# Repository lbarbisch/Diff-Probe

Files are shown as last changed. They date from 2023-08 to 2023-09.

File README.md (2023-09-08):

# Diff-Probe

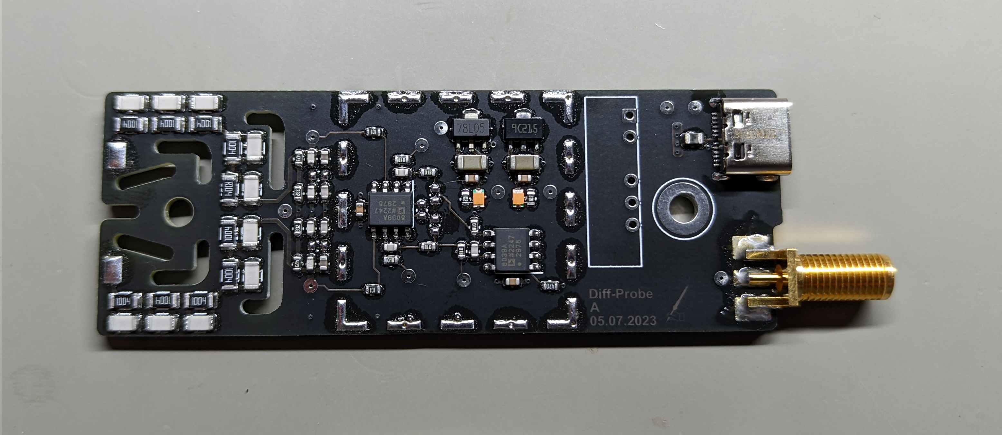
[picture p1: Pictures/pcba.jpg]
Circuit Board


## Overview
The goal of this project was to create a relatively cheap and simple differential probe, intended mostly for hobbyists and makers.

## Specification
This probe has a voltage rating of ±500V on each input, which means a differential rating of ±1000V.  
Depending on the opamps the usable bandwith can be in excess of 10 MHz.  

The power supply is done via a USB-C connector and a DC/DC converter for galvanic isolation.

I've tried two different opamps, with whom the Diff-Probe can reach the following bandwidths:

| Opamp  | Opamp bandwith | Probe bandwidth | Cost per opamp |
| -----  | --- | --- | --- |
| TL072  | 3MHz | ~1MHz | <0.20$ |
| AD8039 | 350MHz | ~18MHz | ~2.50$ |

## Cost
All the components cost about 20 to 25 USD with the more expensive opamp option.

## Housing
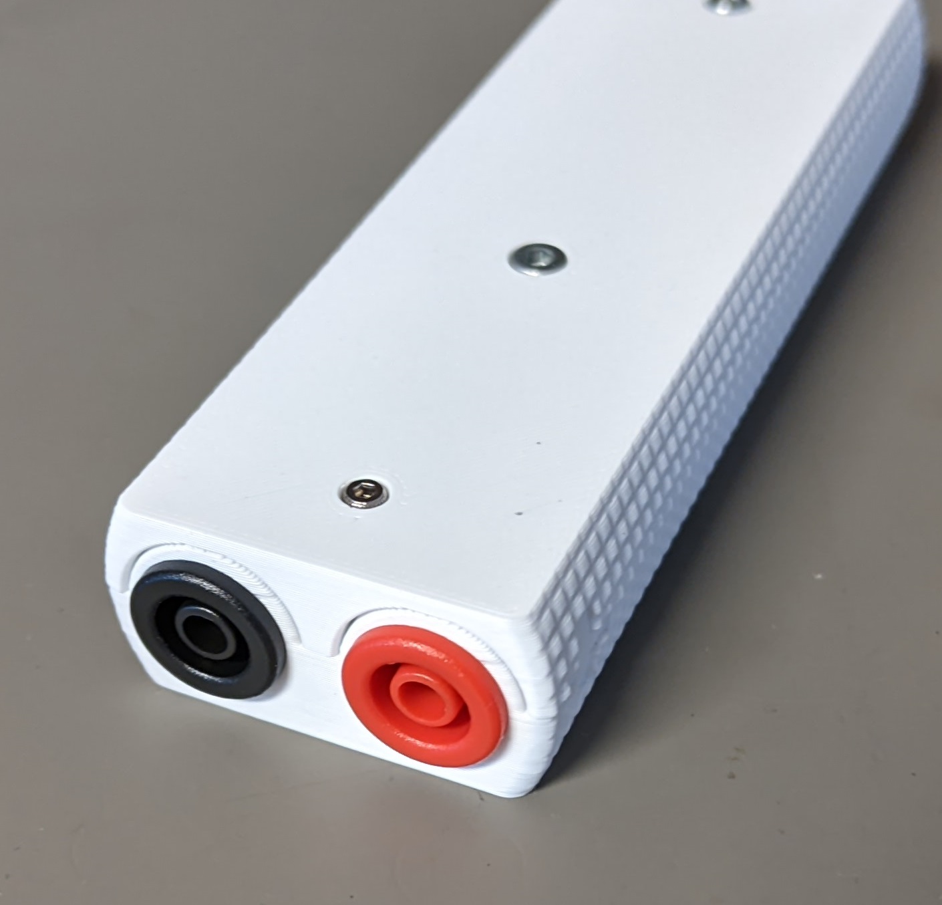
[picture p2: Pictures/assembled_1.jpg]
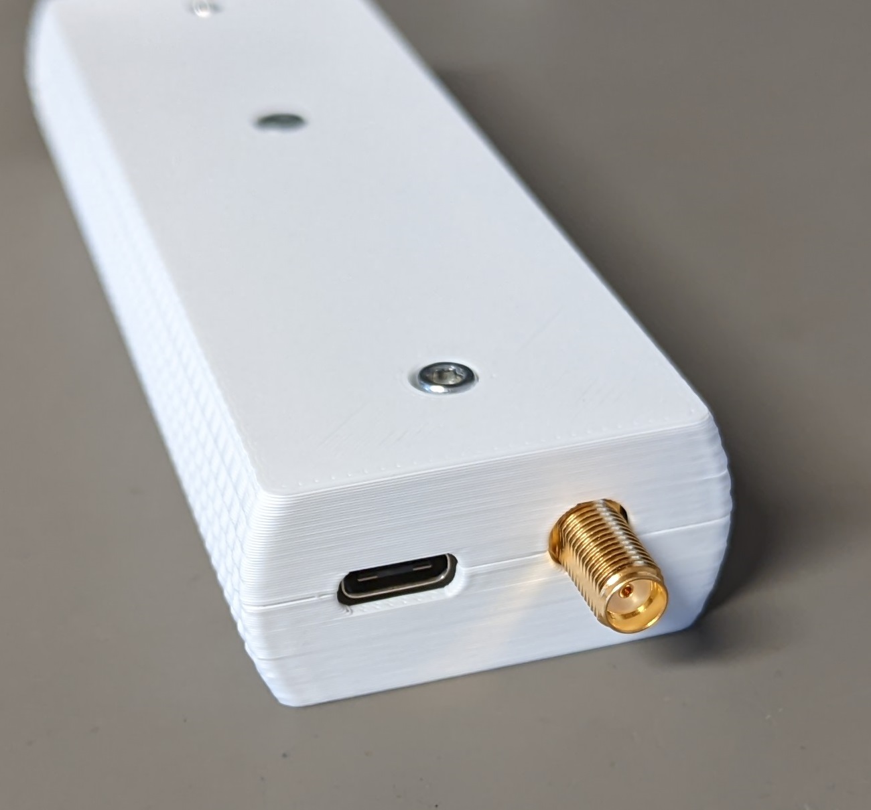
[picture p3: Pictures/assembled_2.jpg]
   
This housing is printed in ABS for durability, but can easily be printed in PLA.  
It is held together with two M3x10 and one M2x12 screw, which are each screwed into heat set inserts.  
The M2 screw can be omitted, but the housing will probably not fully close on that side and leave a small gap.

Assembly of the Diff-Probe:  
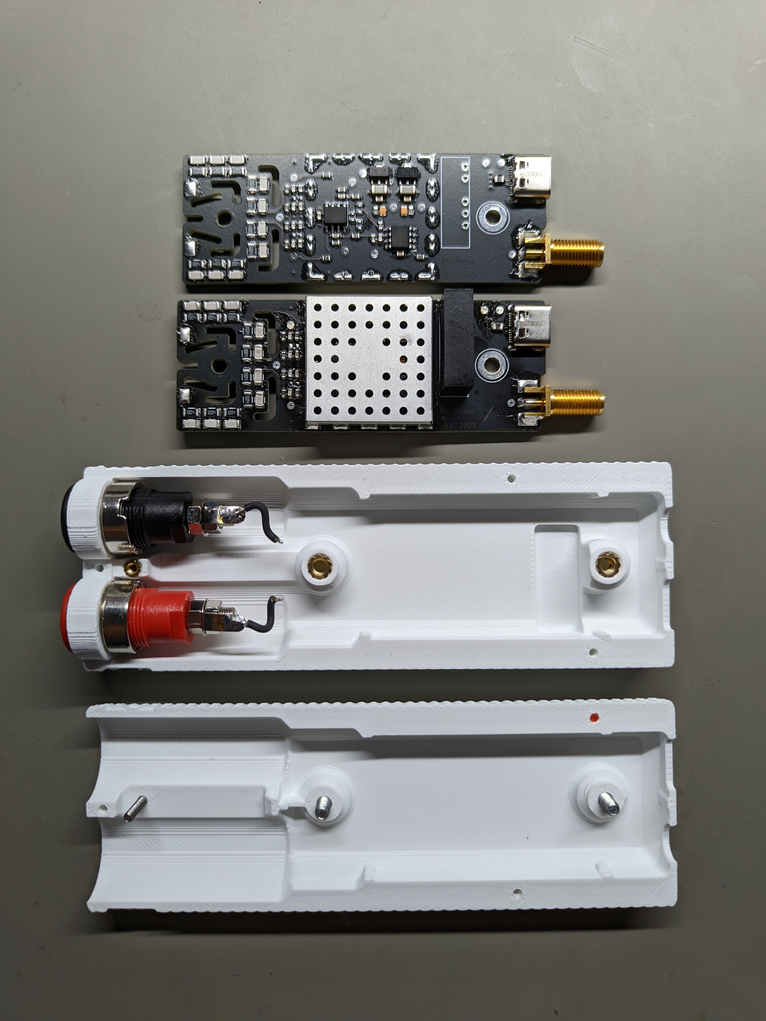
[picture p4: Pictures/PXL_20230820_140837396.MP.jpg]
  

## Files
[Schematic](/PCB/OUTPUT/Diff-Probe_A00_SCH.PDF)  
[Assembly Drawing](/PCB/OUTPUT/Diff-Probe_A00_PCBA.PDF)  
[Bill of Material](/PCB/OUTPUT/Diff-Probe_A00_BOM.xlsx)  

[CAD for Housing](/Housing/)

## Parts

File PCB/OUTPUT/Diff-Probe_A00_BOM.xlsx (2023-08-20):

Bill of Materials
Project: |  | Diff-Probe.PrjPcb
Variant: |  | 951.xxxx
 |  | Base Variant
Revision: |  | A
Creation Date: | 20.08.2023 | 14:23
Print Date: | 2023-08-20 | 14:27:20
 |  | Designator | Quantity | Description | Manufacturer | Manufacturer Part Number | Footprint | ClassName
 |  | C1, C2, C3, C4, C5, C19, C20, C21, C22, C23 | 10 | CAP CER 10PF 1KV U2J 1206 |  |  | C-1206_3216_100_L_RF | Surface_Assy
 |  | C7, C11, C13, C17 | 4 | Cap Cer SMD 10p 50V +/- 0.25pF 0603 C0G | AVX | 06035A100CAT* | C-0603_1608_095_L_RF | Surface_Assy
 |  | C8, C18 | 2 | Cap Cer SMD 470p 100V 10% 0603 X7R | AVX | 06031C471KAT2A | C-0603_1608_095_L_RF | Surface_Assy
 |  | C10, C16, C25 | 3 | Cap Cer SMD 22p 50V 5% 0603 C0G | AVX | 06035A220JAT | C-0603_1608_095_L_RF | Surface_Assy
 |  | C12, C14 | 2 | Cap Cer SMD 330p 50V 2% 0603 C0G | MURATA | GRM1885C1H331GA01D | C-0603_1608_095_L_RF | Surface_Assy
 |  | C26, C27, C29, C31, C34, C38, C41 | 7 | Cap Cer SMD 100n 100V 10% 0603 X7R | MURATA | GRM188R72A104KA35 | C-0603_1608_095_L_RF | Surface_Assy
 |  | C28, C30, C33, C37, C40 | 5 | Cap Cer SMD 10u 6.3V 10% 0805 X7R | MURATA | GCM21BR70J106KE22 | C-0805_2012_155_L_RF | Surface_Assy
 |  | C32, C39 | 2 | Cap Cer SMD 100u 6.3V 20% 1206 X5R | AVX | 12066D107MAT2A | C-1206_3216_180_L_RF | Surface_Assy
 |  | C35, C42 | 2 | Cap Cer SMD 1n 50V 1% 0603 C0G | AVX | 06035A102FAT* | C-0603_1608_100_L_RF | Surface_Assy
 |  | C36, C43 | 2 | Cap Cer SMD 100p 50V 5% 0603 C0G | YAGEO | CC0603J*NPO9BN101 | C-0603_1608_095_L_RF | Surface_Assy
 |  | D1, D2 | 2 | LED Green LTST-C190KGKT 0603 | Lite-On Inc | LTST-C190KGKT | LED-0603_1608_Green_L_RF | Surface_Assy
 |  | N1, N2 | 2 | IC OPAMP JFET 3MHZ 8SOIC | Texas Instruments | TL072IDR | SO8_L_RF | Surface_Assy
 |  | PCB1 | 1 | <PCB DesignName Revision> |  |  | Dummy_PCB-Parameter_SM | Symbol
 |  | R1, R2, R3, R4, R5, R19, R20, R21, R22, R23 | 10 | Res SMD 1M 1% 0.25W 1206 | YAGEO | RC1206FR-071ML | R-1206_3216_065_L_RF | Surface_Assy
 |  | R6, R17 | 2 | Res SMD 100R 1% 0.1W 0603 | YAGEO | RC0603FR-07100RL | R-0603_1608_050_L_RF | Surface_Assy
 |  | R7, R9, R10, R15, R18, R24, R26, R27 | 8 | Res SMD 1k 1% 0.1W 0603 | YAGEO | RC0603FR-071KL | R-0603_1608_050_L_RF | Surface_Assy
 |  | R8, R16 | 2 | Res SMD 47k 1% 0.1W 0603 | YAGEO | RC0603FR-0747KL | R-0603_1608_050_L_RF | Surface_Assy
 |  | R11, R14 | 2 | Res SMD 3k3 1% 0.1W 0603 | YAGEO | RT0603FRE073K3L | R-0603_1608_050_L_RF | Surface_Assy
 |  | R12 | 1 | Res SMD 47R 1% 0.1W 0603 | YAGEO | RC0603FR-0747RL | R-0603_1608_050_L_RF | Surface_Assy
 |  | R25 | 1 | Res SMD 0R 1% 0.125W 0805 | YAGEO | RC0805JR-070RL | R-0805_2012_060_L_RF | Surface_Assy
 |  | R28, R29 | 2 | Res SMD 5k1 1% 0.1W 0603 | YAGEO | RC0603FR-075K1L | R-0603_1608_050_L_RF | Surface_Assy
 |  | U1 | 1 | IC DC/DC Converter 5VIN +-9VOUT 1W | XP Power | IA0509S | SIP7 | Through-Hole_Assy
 |  | V1, V2, V3, V4 | 4 | Diode Schottky 40V 1A SMA | VISHAY | SS14-E3 | SMA_DO214AC_L_RF | Surface_Assy
 |  | V5 | 1 | IC REG 5V SOT-89-3 | ST | L78L05 | SOT-89-3 | Surface_Assy
 |  | V6 | 1 | IC REG -5V SOT-89-3 | ST | L79L05 | SOT-89-3 | Surface_Assy
 |  | X2 | 1 | EMI Shield 26.2mm x 26.2mm, soldered | Laird | BMI-S-103 | BMI-S-103 | Surface_Assy | Testpoint | Through-Hole_Assy | NetTie | Symbol | Mechanical
 |  | X3 | 1 | CONN USB-C 16pin | Molex | 105450-0101 | 105450-0101 | Through-Hole_Assy
 |  | X4 | 1 | CONN RF SMA | MOLEX | 73251-2120 | 73251-2120 | Through-Hole_Assy
 |  |  | 82

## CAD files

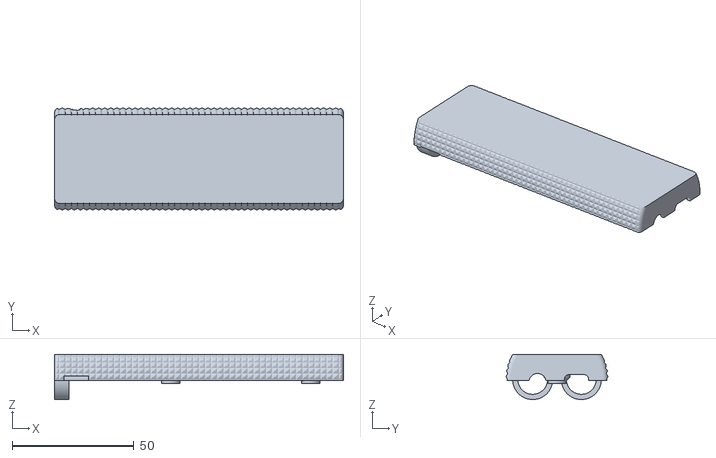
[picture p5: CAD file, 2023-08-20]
Housing/case_knurls - Part 2.stl
118.9 x 41.9 x 18.6

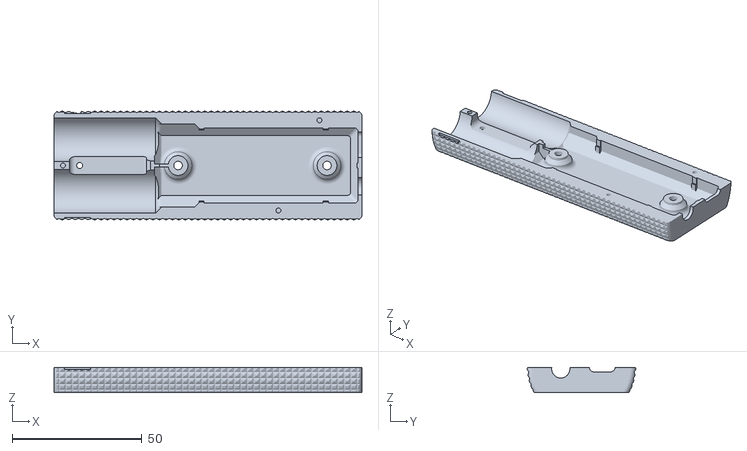
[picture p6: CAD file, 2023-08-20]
Housing/case_knurls - Part 1.stl
118.9 x 41.9 x 9.75

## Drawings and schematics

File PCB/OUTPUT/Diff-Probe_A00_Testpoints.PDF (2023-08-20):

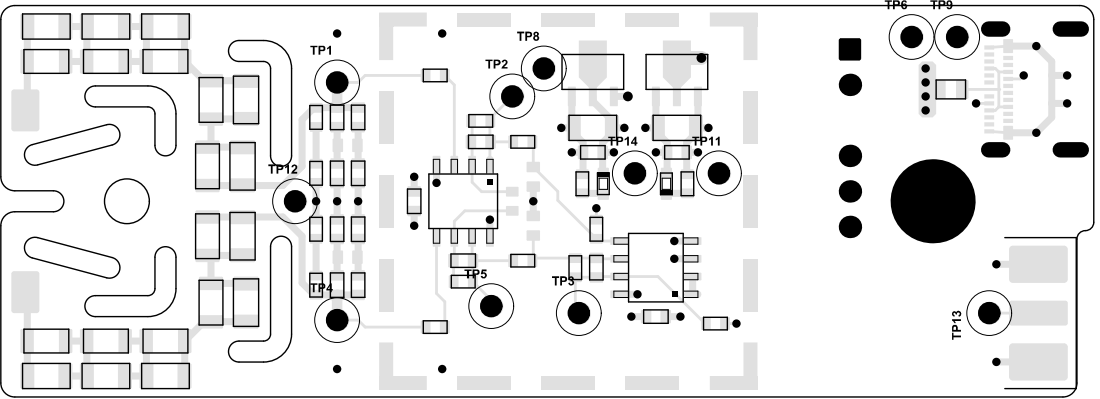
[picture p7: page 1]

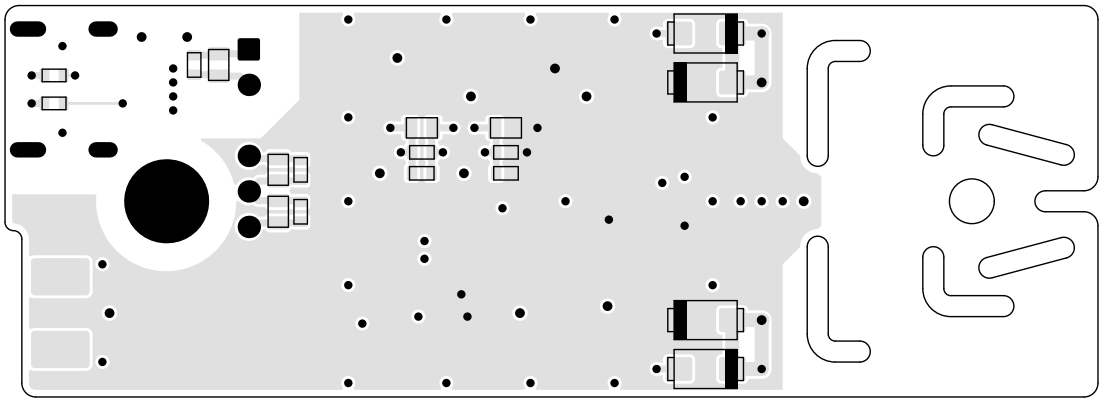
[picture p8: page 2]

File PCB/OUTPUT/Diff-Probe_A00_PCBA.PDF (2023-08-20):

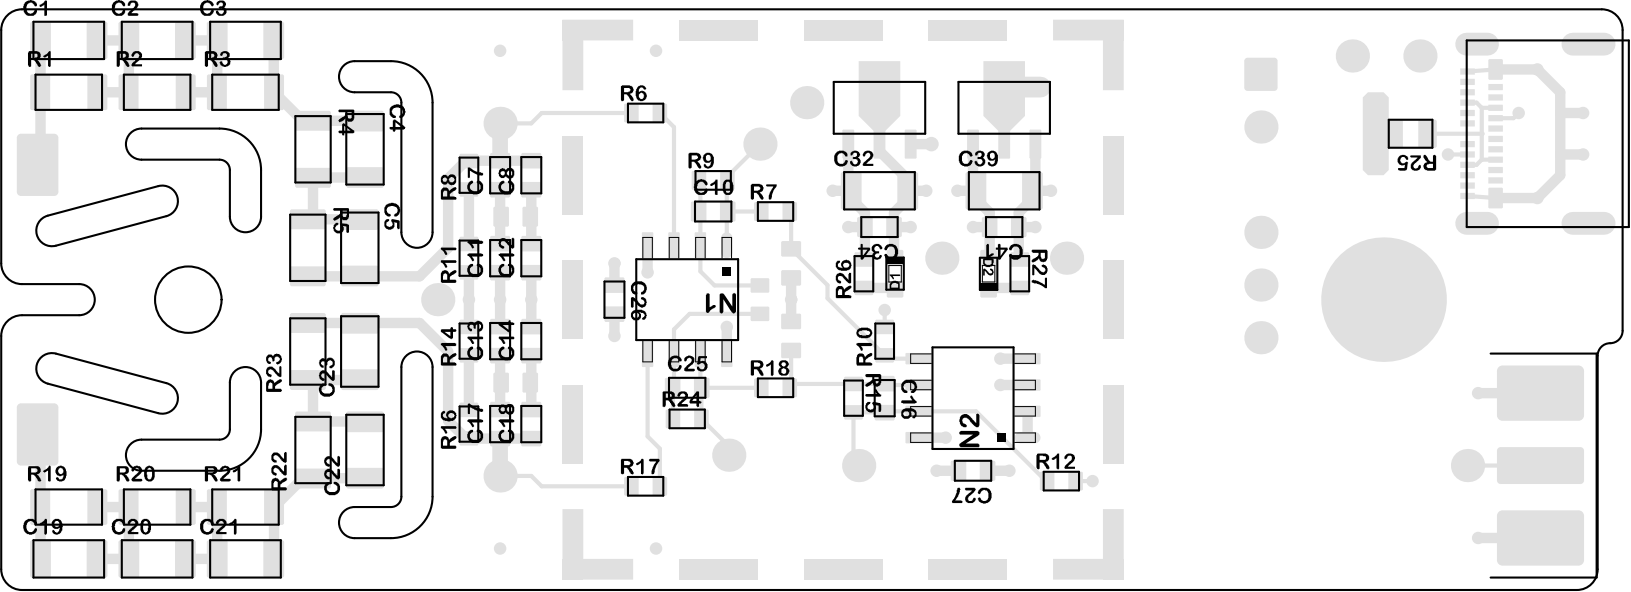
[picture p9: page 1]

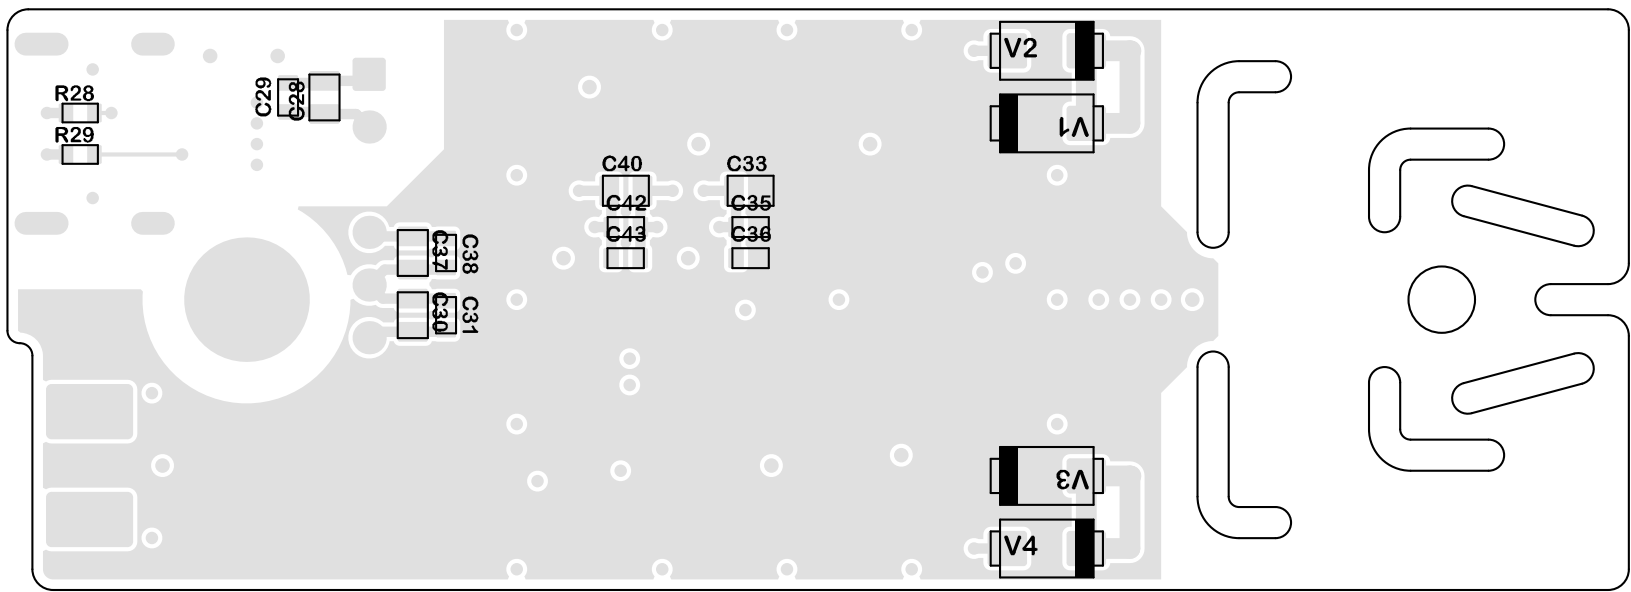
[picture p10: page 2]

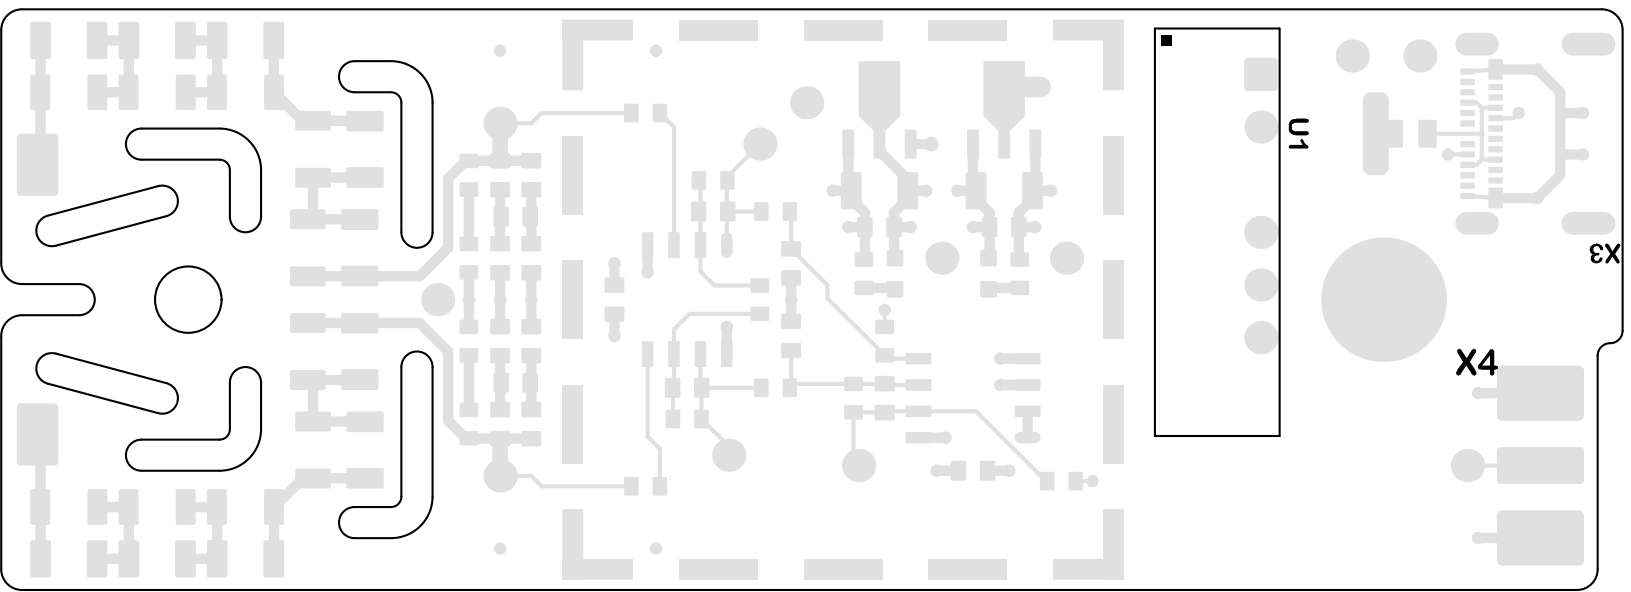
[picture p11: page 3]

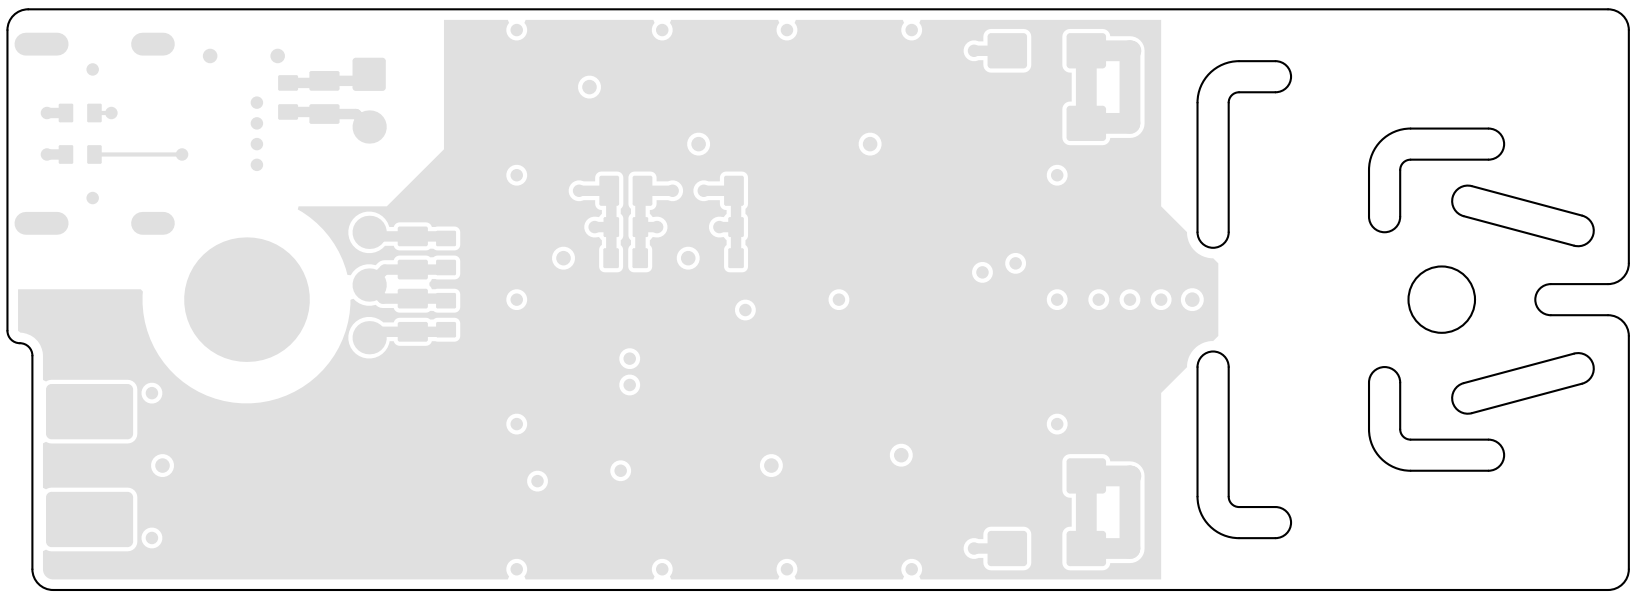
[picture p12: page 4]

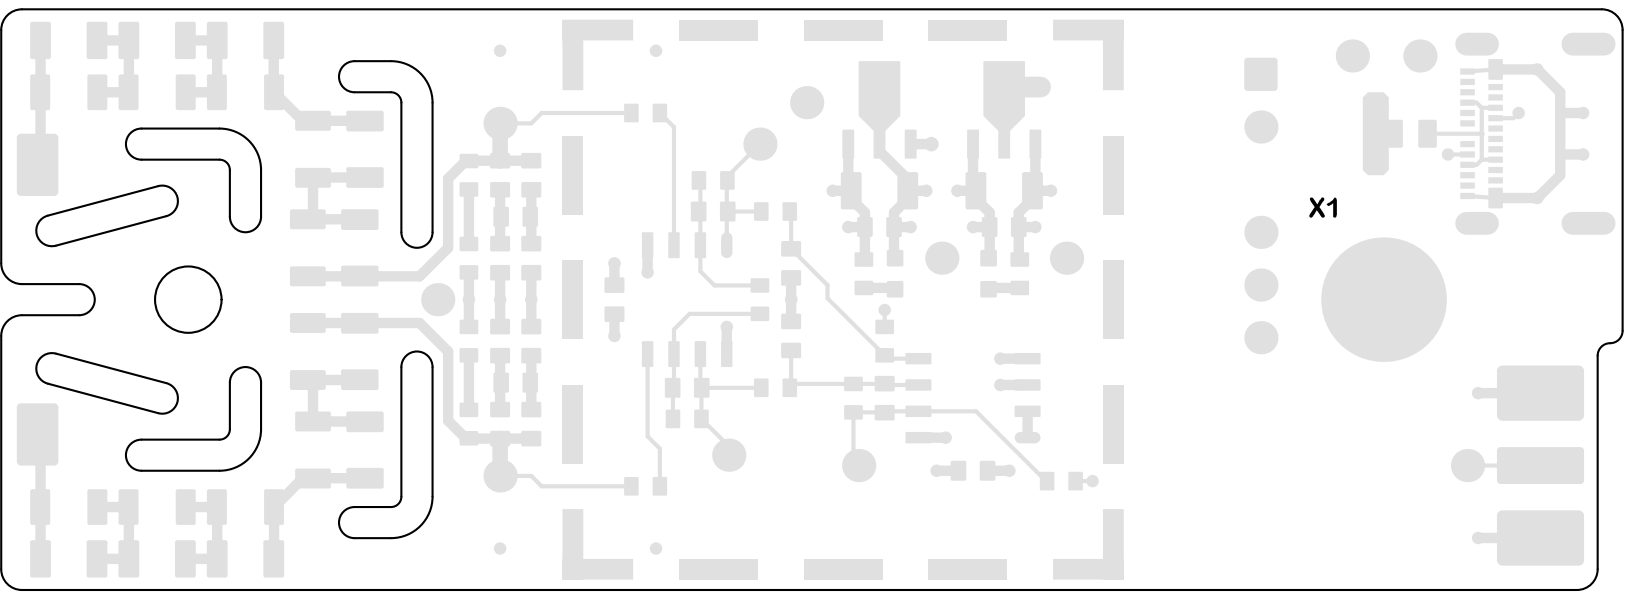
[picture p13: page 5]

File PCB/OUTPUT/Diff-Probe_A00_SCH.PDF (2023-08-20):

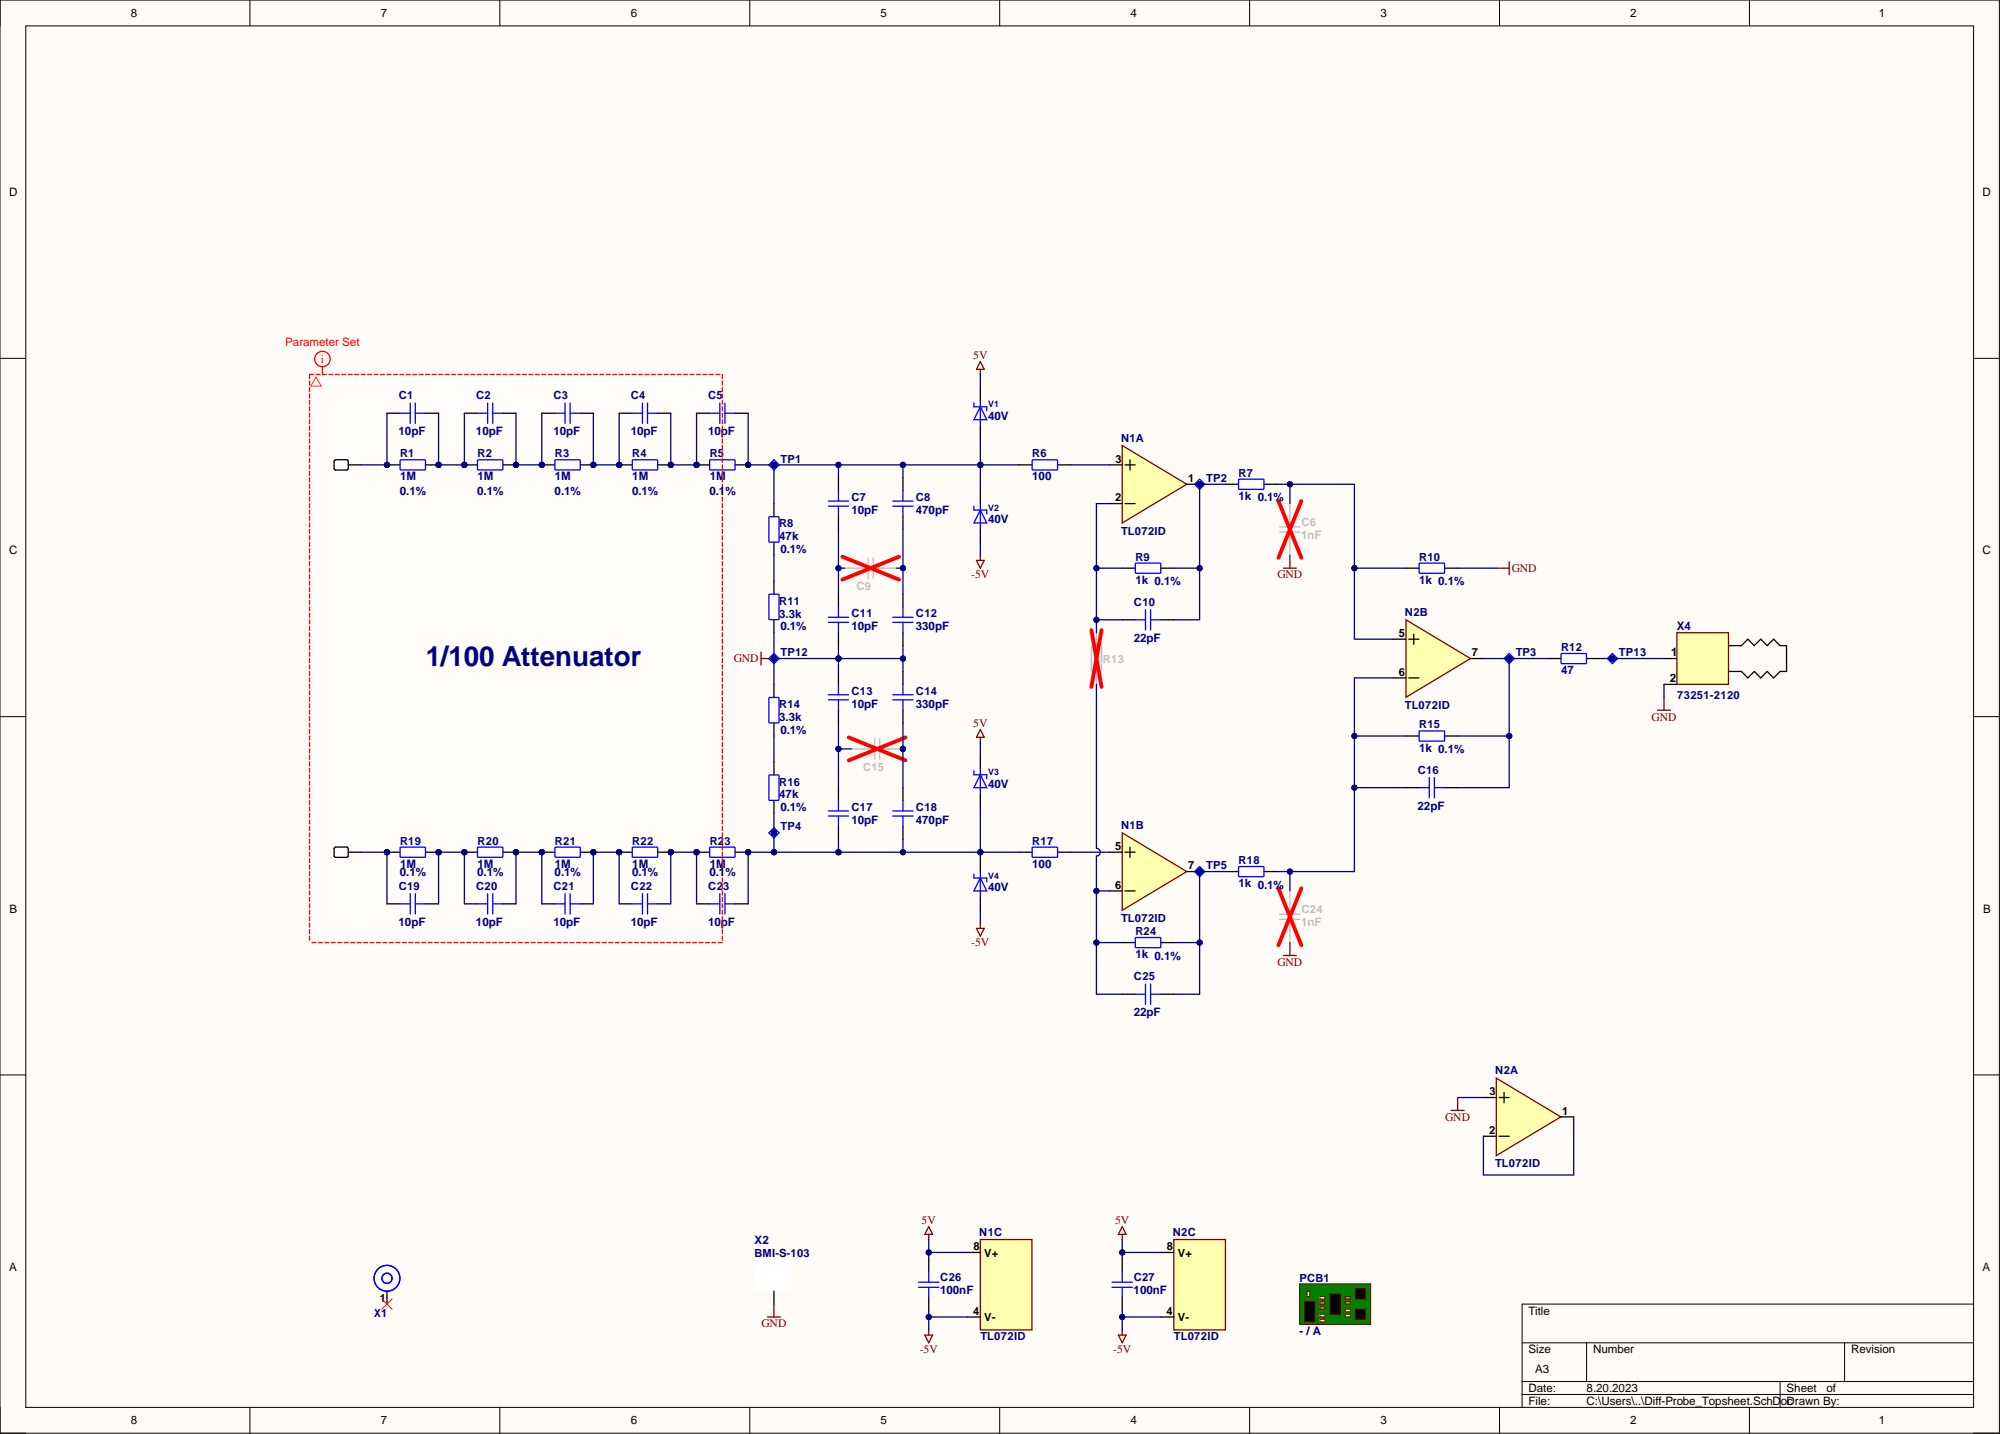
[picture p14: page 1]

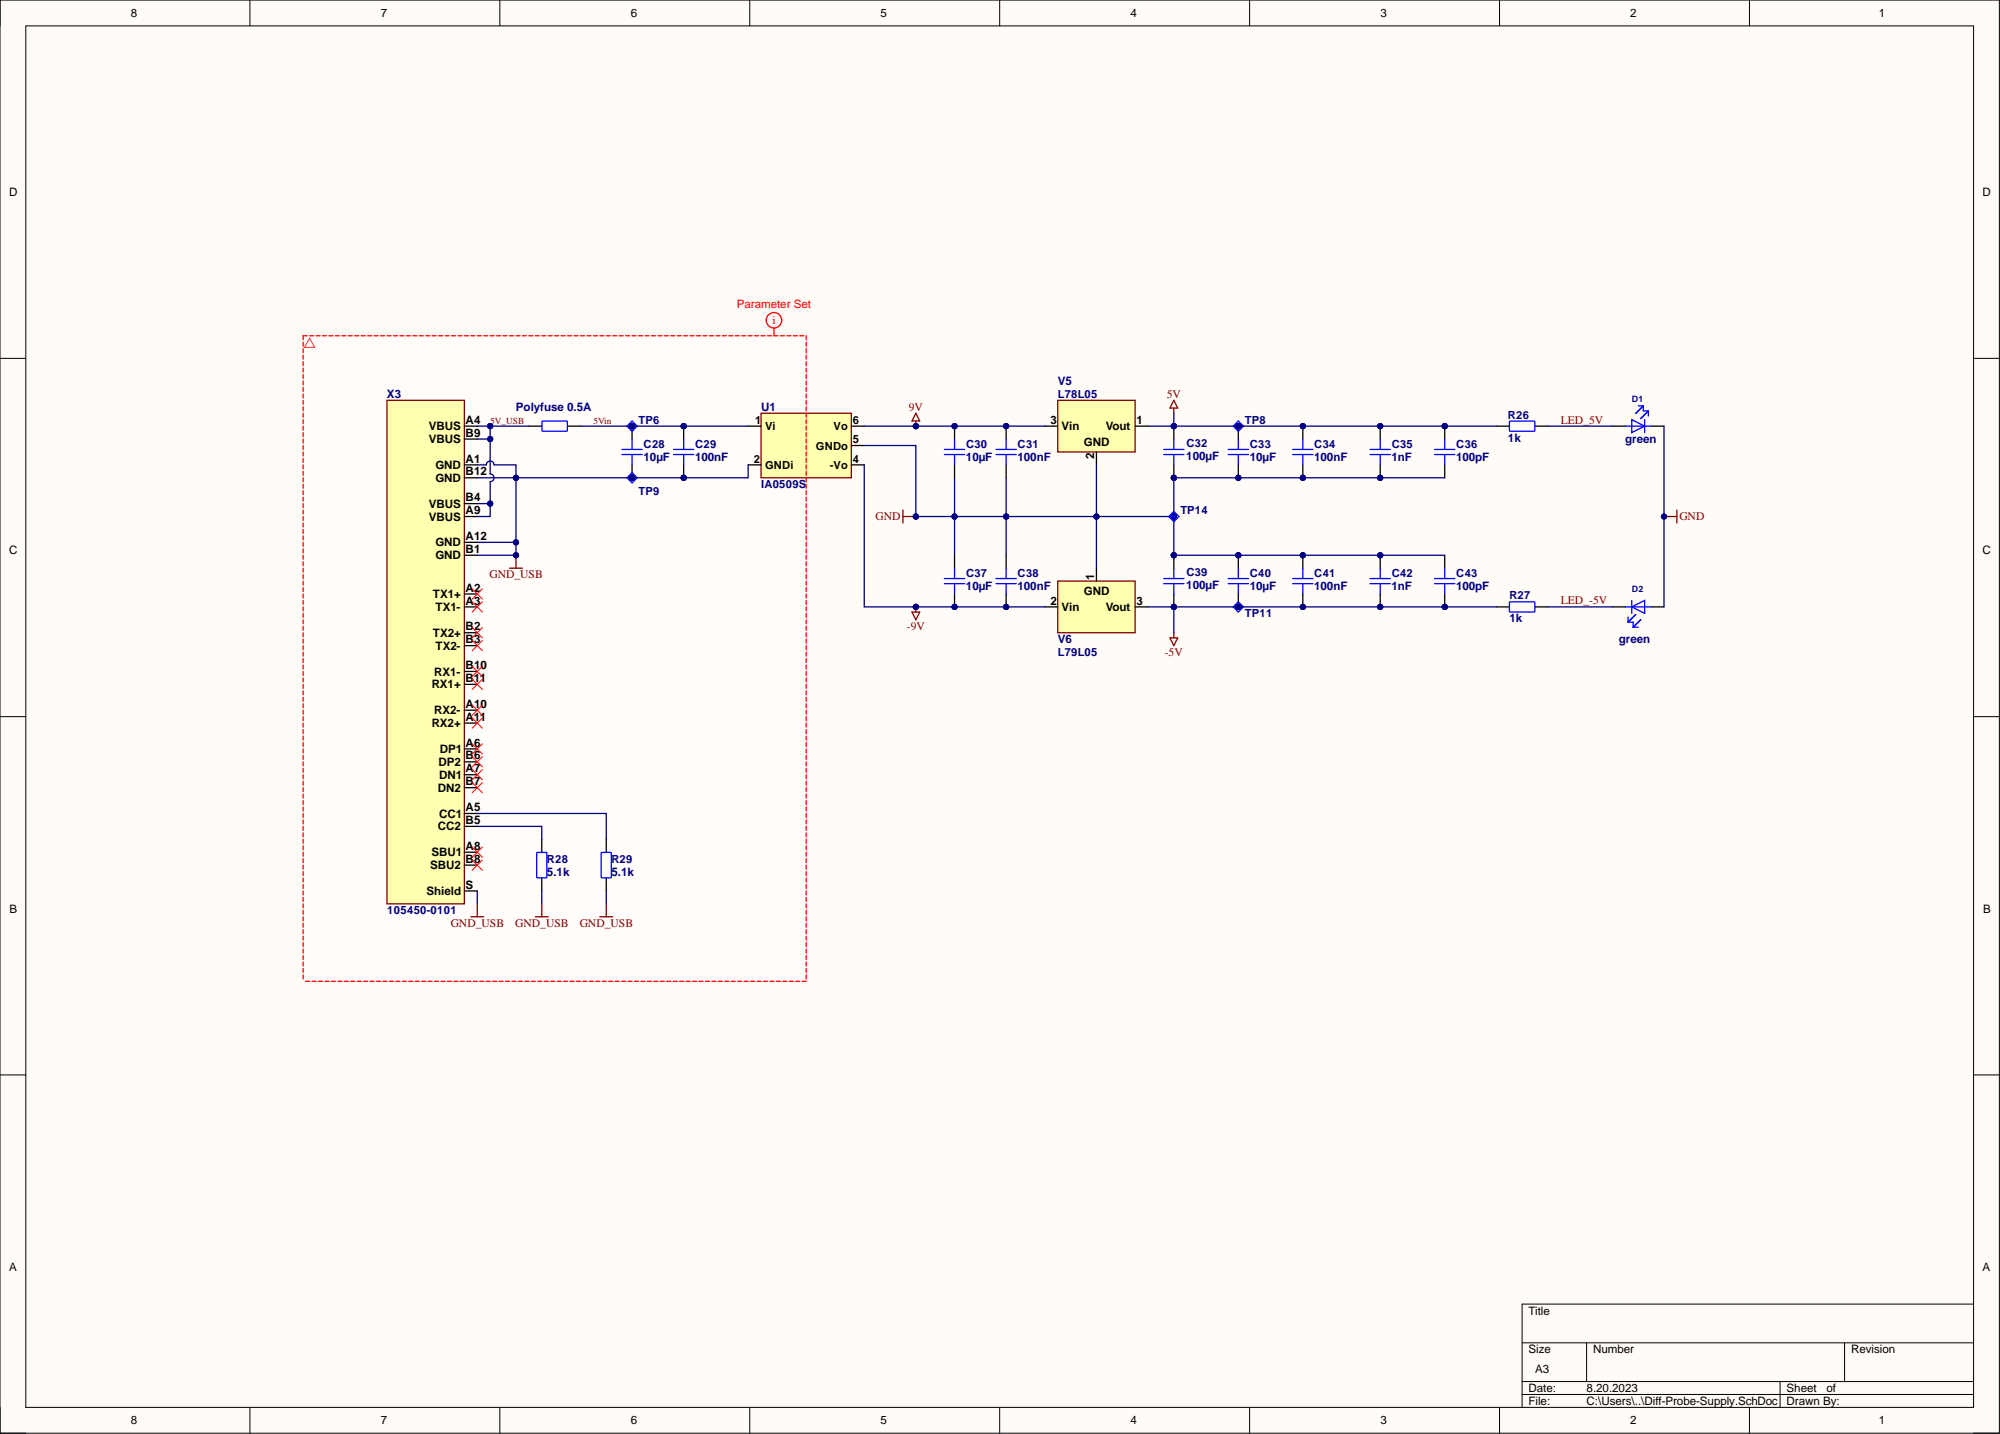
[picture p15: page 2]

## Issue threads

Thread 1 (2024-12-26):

Choice of resistor R8 R11

ddieffen, 2024-12-26:
Hello,
I might misunderstand something but why R8 and R11 add up to 50.3k?
To my comprehension this would set the divisor to 5M/50.3k although it is possible to source a 3kOhms resistor for R11and make the ratio closer to 1/100 ?
Thanks

lbarbisch, 2024-12-27:
You're correct, that would be a better fit.
I believe I did it like this, because that was what I had on hand at the time.
For a future version I would add trim pots to have the gain adjustable to trim out tolerances.

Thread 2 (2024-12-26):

Virtual ground with N2A

ddieffen, 2024-12-26:
Hello,
Wouldn't it be possible to keep the +9/-9v out of the DcDc converter and use N2A opamp to balance the virtual ground?
This might save a few components (especially 7805 and 7905) and maintain the power rails at +9 and -9v

lbarbisch, 2024-12-27:
Just leaving the two regulators away would certainly work assumed the opamp is still happy with the +-9V (which the AD8039 is not).
N2A would not be needed for the virtual ground, since the DC/DC converter already provides a ground potential on the output.

The idea behind the linear regulators is to smooth out some of the noise from the switching regulator.
But I haven't done any measurements to support this idea. It could be, that this is not required.
